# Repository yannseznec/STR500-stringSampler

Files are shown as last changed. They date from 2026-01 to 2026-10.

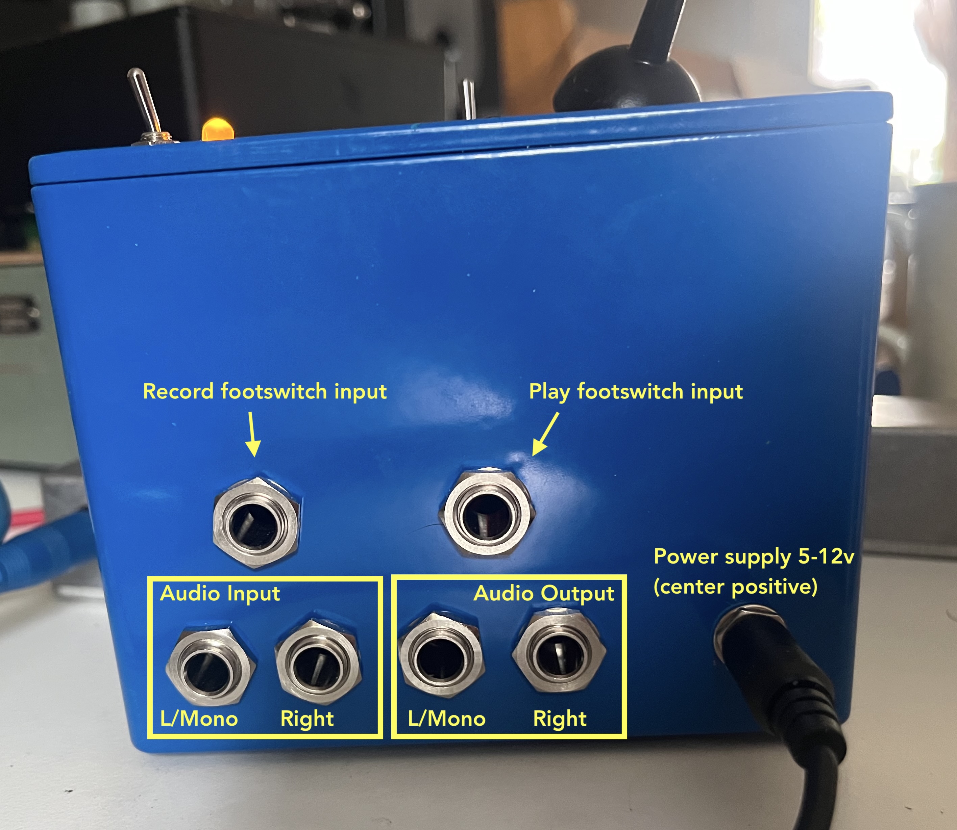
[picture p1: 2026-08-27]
build_notes_etc/STR500_sockets.jpg

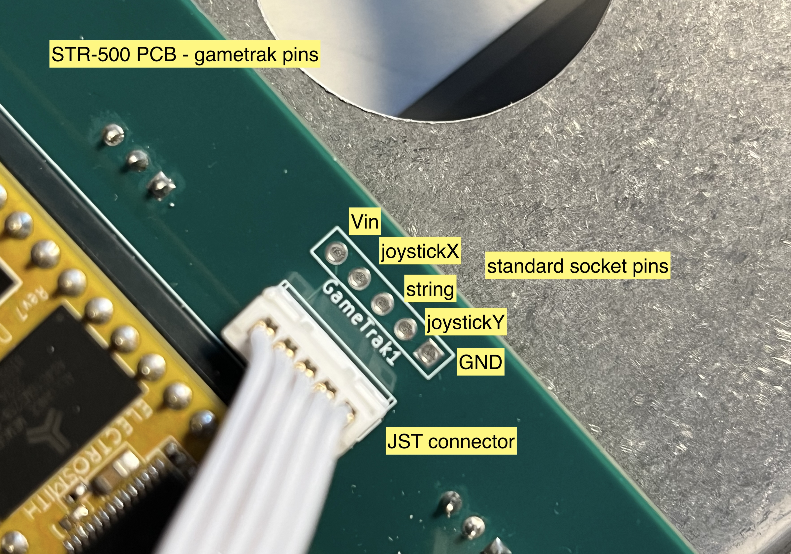
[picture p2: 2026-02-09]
build_notes_etc/picture_gametrak_pins.jpg

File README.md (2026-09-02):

## STR-500

This is all of the code and build info for the STR-500 gestural granular synthesizer. 

It is a granular synthesizer built for the Daisy Seed which uses a salvaged Gametrak string controller to playback a recorded sample. 

Here you will find a Pure Data system for running on the Daisy Seed, a KiCad project with the schematic and PCB design for the instrument, and a folder of information about the physical build. Current working version is called v1.2, and as it stands includes updated code and KiCad (full details on the build are not yet updated).

To-do: 
- develop this Readme
- add an actual to-do list to this Readme

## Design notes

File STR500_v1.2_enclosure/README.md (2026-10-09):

# STR-500 enclosure design 

This folder has the files I use for drilling and etching the enclosure for the STR-500. 

The enclosure I use is a Hammond 1590V. 

The Gametrak string mechanism I'm using is a particular size and shape, which means the enclosure needs to be a certain height and width. I wanted something that I could buy off the shelf (rather than 3D print or build from scratch), and I really like metal enclosures. The Hammond 1590V fulfills all of these requirements - just! It's a very tight fit in there and the holes need to be drilled just right. The only issue is that it's a relatively unusual model, so I can't use the standard drill/paint services that most effects and instrument companies use. 

Instead, the process is: 
• buy the bare metal enclosures
• use a little jig I laser cut to drill all the holes in the enclosure - these have to be pretty accurate because the PCB needs to mount underneath the lid
• get them powder coated blue at an industrial painting place
• put the lids into a laser cutter and etch the powder coating away in the design I want
• fill the etching with a wax crayon, wipe the excess with rubbing alcohol
• light spraypaint for texture

The painting and etching is, of course, totally optional. You can definitely make your own design or just leave it bare metal and unlabeled. 

If you want to follow my own process, the files are all here for you to laser cut your own drill guide. You may find some other useful method for drilling the holes. 

Drilling the holes accurately is challenging! I would recommend first drilling small holes (2-3mm) and then using a stepped bit to get them up to size. The large hole for the Gametrak string is particularly hard to get just right. I usually end up needing to adjust the exact horizontal placement of the Gametrak string using washers on the M5 bolts holding it in place.

Software-wise, the vectors files for the hole locations are made in Affinity, and the laser cutting files are for Lightburn.

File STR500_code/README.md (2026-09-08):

# Granular sampler for Daisy (STR-500)
This is a granular sampling system that runs on a Daisy Seed microcontroller. As the name implies, this is the new version of the code, which I mainly did in an attempt to make it more efficient. That failed, but it resulted in patches that are much cleaner, easier to read, and easier to maintain. So that's something.  

Written in Pure Data. The easiest way to get it running on a Seed is to use PlugData for compiling. I use the "Big + SDRAM" SRAM setting in the compiler to allow for the relatively long sampling time. I set the blocksize to 100 for now. 

This granular patch is essentially the same as the ys.granular system also available here on my github: https://github.com/yannseznec/ys.granular

The main difference is that this version does not use the [clone] object, which is not supported by the Heavy compiler required by the Daisy Seed. There are probably a few other similar changes that I can't remember right now.

This patch is particularly designed for use with a Gametrak string controller, resulting in a gestural sampling machine that I call the STR-500. More details on that coming at some point, you can see videos of it on my instagram if you like: https://www.instagram.com/p/DPdloWzjOOb/

For the STR-500 on Daisy Seed there is a JSON file (STR500_definitions.json) included for getting the interface elements (buttons, switches, Gametrak) connected to the Seed correctly. At some point I'll make a more detailed guide for how to get that to work.

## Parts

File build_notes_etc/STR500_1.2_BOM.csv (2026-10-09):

Part | Number per device | Link | Notes | Secondary link | Notes
IC socket for Daisy | 2 | https://www.electrokit.com/hylslist-2.54mm-1x20p |  | https://se.rs-online.com/web/p/pcb-sockets/2053211
Small buttons | 2 | https://www.electrokit.com/en/tryckknapp-pcb-6x6x12mm-svart
Bigger buttons | 2 | https://se.rs-online.com/web/p/taktila-stromstallare/7651563 |  | https://www.digikey.se/sv/products/detail/mec-switches/5GTH935/2411559 | MEC 5GTH935
Big button caps | 2 | https://se.rs-online.com/web/p/taktila-stromstallartoppar/7651324 |  | https://www.digikey.se/sv/products/filter/tillbehör-lock/210?s=N4IgTCBcDaILYFMDGACAjAEwM4gLoF8g | So many nice colors possible, not all easy to find.
Switches RND 210-00471 | 3 | https://www.electrokit.com/en/vippomkopplare-sub-miniatyr-1-pol-on-on-pcb |  | https://www.digikey.se/en/products/detail/e-switch/200MSP1T1B1M2QEH/378916 | Need to check the Digikey ones to see, I think they are better. Main thing is 3 pin with .1” spacing
Capacitors | 2 |  |  |  | 1 electrolytic 220µf, 1 .1µf ceramic
Resistor | 1 |  |  |  | 220ohm (roughly, for LED)
LED | 1 |  |  |  | I use 5mm
Molex 6pin connectors | 1 | https://www.electrokit.com/en/kontakt-kk-pcb-2.54mm-6-pol | https://se.farnell.com/multicomp-pro/mc34635/header-square-pin-2-54mm-6way/dp/1675768 |  | For the foot switch connector. If not using foot switches you can avoid this and just bridge four pins (see the build notes)
Molex 2pin connectors | 5 | https://se.farnell.com/multicomp-pro/mc34629/header-tht-vertical-2-54mm-2way/dp/1675764 |  |  | For audio in/out and power connector. You can choose other connection options using the 2.54” holes
JST connector | 1 | https://www.electrokit.com/en/stiftlist-ph-5-pol-2.0mm |  |  | For easy Gametrak connection. Other connection options available, see build notes
M5 screws | 4 | https://se.rs-online.com/web/p/maskinskruv/9087719 |  |  | For gametrak mounting. 45 or 50mm
M5 nuts | 4 | https://se.rs-online.com/web/p/sexkantsmuttrar/2874065 |  |  | For gametrak mounting
M5 standoffs | 4 | https://www.electrokit.com/en/distanshylsa-m5-10mm-metall |  | https://www.digikey.se/en/products/detail/würth-elektronik/970120581/6174778 | 12mm might be better! Try them on next Digikey order
M5 hole washers |  |  |  |  | Useful for adjusting Gametrak mounting distance
M3 standoffs | 2 | https://se.rs-online.com/web/p/distansbultar/1842769 |  |  | 8mm. For PCB lid mounting
M3 screws | 2 | https://se.rs-online.com/web/p/maskinskruv/0553396 |  | https://se.rs-online.com/web/p/hylsskruv/4839751 | PCB lid mounting
M3 nuts | 2 | https://se.rs-online.com/web/p/sexkantsmuttrar/0560293 |  |  | PCB lid mounting
Power socket | 1 | https://www.electrokit.com/en/dc-jack-2.1mm-chassi-rund-brytande |  |  | 2.1mm pin
2 pin molex | 5 | https://se.farnell.com/multicomp-pro/mc34481/crimp-housing-2-54mm-2way/dp/1675754 |  |  | If you want to crimp your own
6 wire molex cables | 1 | https://www.electrokit.com/en/kontakthus-kk-med-kabel-6-pol-20cm |  |  | Pre-crimped cables for lazy people like me
2 wire molex cable | 1 | https://www.electrokit.com/en/kontakt-kk-pcb-2.54mm-2-pol |  |  | Pre-crimped cables for lazy people like me
Audio Jack sockets | 6 | https://se.rs-online.com/web/p/jackkontakter-och-uttag/2617666?referrer=distrelec | Amphenol - ACJS-MVS-2S | https://www.digikey.be/en/products/detail/amphenol-sine-systems-corp/ACJM-MVS-2S/10443648 | Switching audio sockets for mono/stereo. See build notes.
Power supply | 1 | https://se.rs-online.com/web/p/acdc-adaptrar/0634220 |  |  | 5-12v, center positive
Enclosure | 1 | https://www.electrokit.com/en/aluminiumlada-gjuten-1590v-ip54-119x119x90mm
Jumper cap | 2 | https://se.rs-online.com/web/p/byglar-och-shuntar/2518682?matchtype=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 |  |  | Optional - for bridging the footswitch pins
Gametrak | 1 |  |  |  | I use the later model gametrak, looks like a TIE fighter, check my videos for more info
Daisy Seed | 1 | https://daisy.audio/products/seed3 |  |  | Older Seed 2 also works

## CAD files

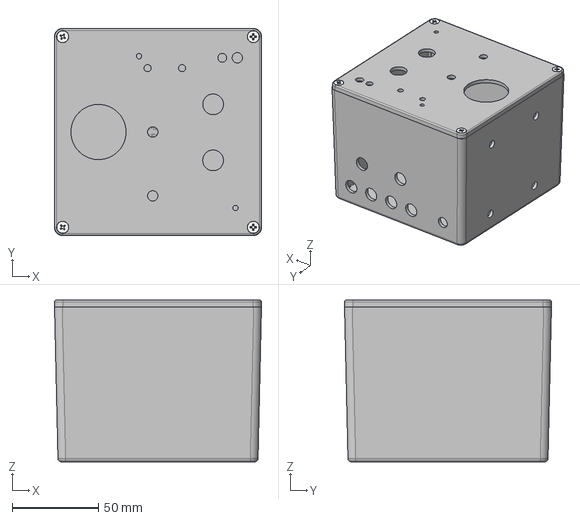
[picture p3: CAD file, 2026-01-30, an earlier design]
old_version_things/STR500_v1.1_enclosure/yanns_box_jan21.step
120.0 x 120.0 x 93.8 mm
1590V Box
1590Q-U-V Lid

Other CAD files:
STR500_v1.2_enclosure/str5001.2_lid_full.dxf
old_version_things/STR500_v1.1_enclosure/STR500_1-1_drill_drawings/STR500+Drawing+gametrak.dwg
old_version_things/STR500_v1.1_enclosure/STR500_DXF_from_PCB/Side_gametrak_drill.dxf
STR500_v1.1_enclosure/STR500_1-1_drill_drawings/STR500+Drawing+lid.dwg
STR500_v1.1_enclosure/STR500_DXF_from_PCB/Side_gametrak_drill.dxf
old_version_things/STR500_v1.1_enclosure/STR500_1-1_drill_drawings/STR500+Drawing+lid.dwg
old_version_things/STR500_v1.1_enclosure/STR500_DXF_from_PCB/Side_sockets_drill.dxf
old_version_things/STR500_v1.1_enclosure/yanns_box.step
STR500_v1.1_enclosure/STR500_1-1_drill_drawings/STR500+Drawing+gametrak.dwg
STR500_v1.1_enclosure/STR500_DXF_from_PCB/Side_sockets_drill.dxf
STR500_v1.1_enclosure/yanns_box.step
old_version_things/STR500_v1.1_enclosure/STR500_1-1_drill_drawings/STR500+Drawing+sockets.dwg
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

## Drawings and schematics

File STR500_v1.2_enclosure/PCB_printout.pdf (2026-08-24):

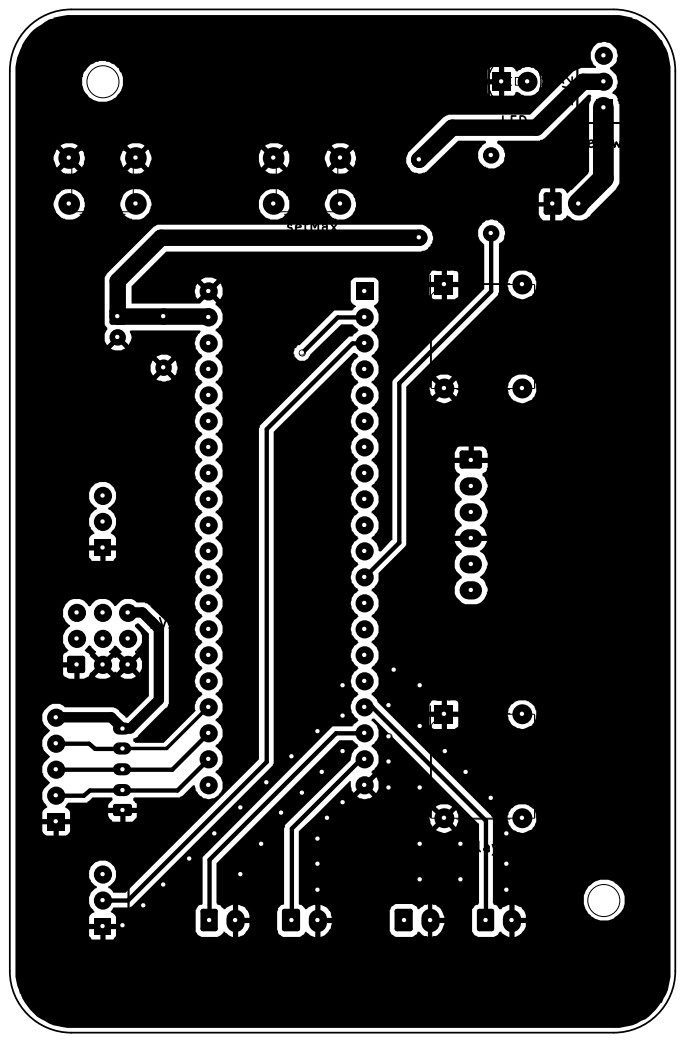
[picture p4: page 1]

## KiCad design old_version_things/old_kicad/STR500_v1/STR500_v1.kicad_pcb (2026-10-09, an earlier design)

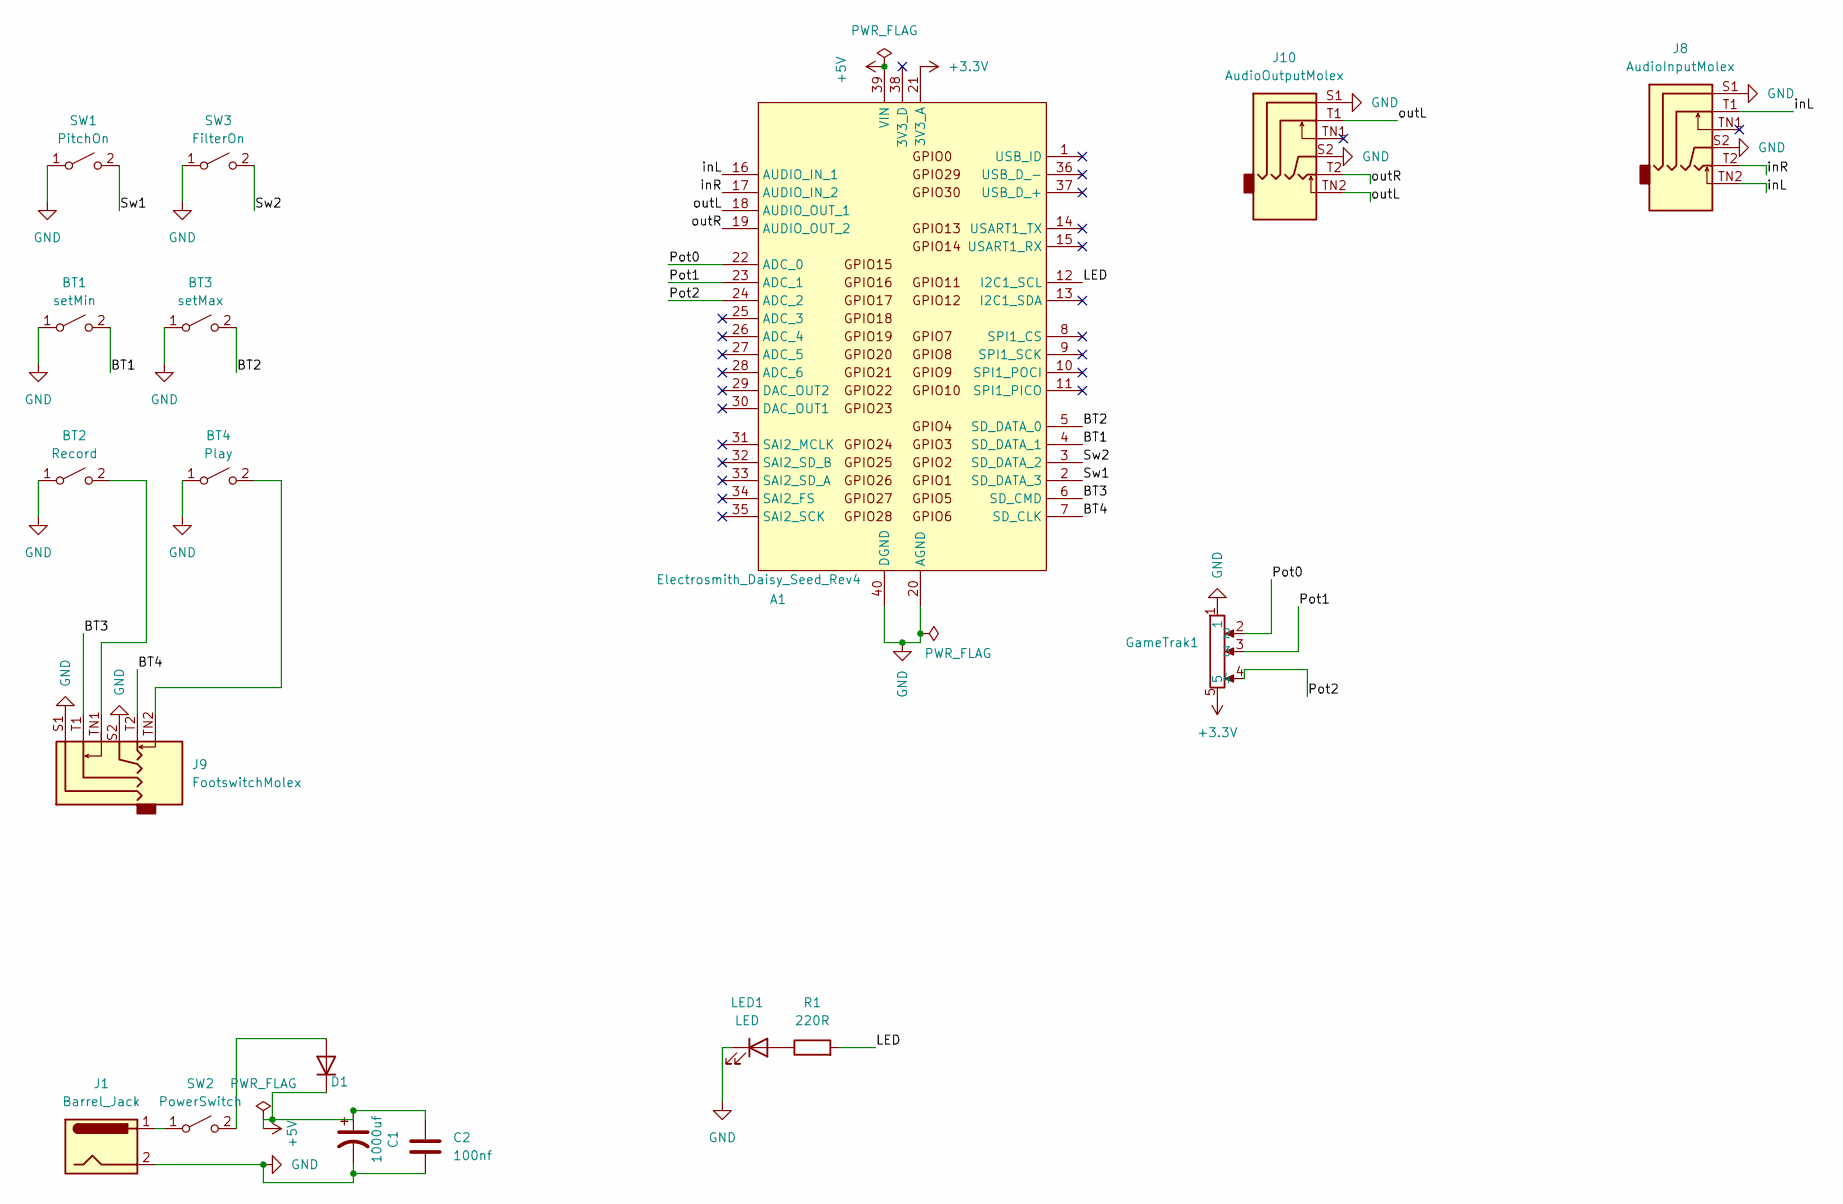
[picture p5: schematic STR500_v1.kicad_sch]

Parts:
A1: Electrosmith_Daisy_Seed_Rev4; Electrosmith_Daisy_Seed
BT1: setMin; SW_PUSH_6mm
BT2: Record; SW_TS13-1212-73-BK-160-D
BT3: setMax; SW_PUSH_6mm
BT4: Play; SW_TS13-1212-73-BK-160-D
C1: 1000uf; CP_Radial_D5.0mm_P2.00mm
C2: 100nf; C_Disc_D5.0mm_W2.5mm_P5.00mm
D1: D; R_Axial_DIN0207_L6.3mm_D2.5mm_P7.62mm_Horizontal
GameTrak1: Molex_Micro-Latch_53253-0570_1x05_P2.00mm_Vertical
J1: Barrel_Jack; Molex_KK-254_AE-6410-02A_1x02_P2.54mm_Vertical
J8: AudioInputMolex; Molex_sixpin_twoJacks
J9: FootswitchMolex; Molex_sixpin_twoJacks
J10: AudioOutputMolex; Molex_sixpin_twoJacks
LED1: LED; LED_D5.0mm
R1: 220R; R_Axial_DIN0207_L6.3mm_D2.5mm_P7.62mm_Horizontal
SW1: PitchOn; submini_toggle
SW2: PowerSwitch; submini_toggle
SW3: FilterOn; submini_toggle

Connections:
+3.3V: A1.21 (3V3_A), GameTrak1.5
+5V: A1.39 (VIN), C1.1, C2.1, D1.1 (K)
/BT1: A1.4 (SD_DATA_1), BT1.2 (B)
/BT2: A1.5 (SD_DATA_0), BT3.2 (B)
/BT3: A1.6 (SD_CMD), J9.T1
/BT4: A1.7 (SD_CLK), J9.T2
/LED: A1.12 (I2C1_SCL), R1.2
/Pot0: A1.22 (ADC_0), GameTrak1.2
/Pot1: A1.23 (ADC_1), GameTrak1.3
/Pot2: A1.24 (ADC_2), GameTrak1.4
/Sw1: A1.2 (SD_DATA_3), SW1.2 (B)
/Sw2: A1.3 (SD_DATA_2), SW3.2 (B)
/inL: A1.16 (AUDIO_IN_1), J8.T1, J8.TN2
/inR: A1.17 (AUDIO_IN_2), J8.T2
/outL: A1.18 (AUDIO_OUT_1), J10.T1, J10.TN2
/outR: A1.19 (AUDIO_OUT_2), J10.T2
GND: A1.20 (AGND), A1.40 (DGND), BT1.1 (A), BT2.1 (A), BT3.1 (A), BT4.1 (A), C1.2, C2.2, GameTrak1.1, J1.2, J8.S1, J8.S2, J9.S1, J9.S2, J10.S1, J10.S2, LED1.1 (K), SW1.1 (A), SW3.1 (A)
unnamed: BT2.2 (B), J9.TN1
unnamed: BT4.2 (B), J9.TN2
unnamed: D1.2 (A), SW2.2 (B)
unnamed: LED1.2 (A), R1.1
unnamed: J1.1, SW2.1 (A)

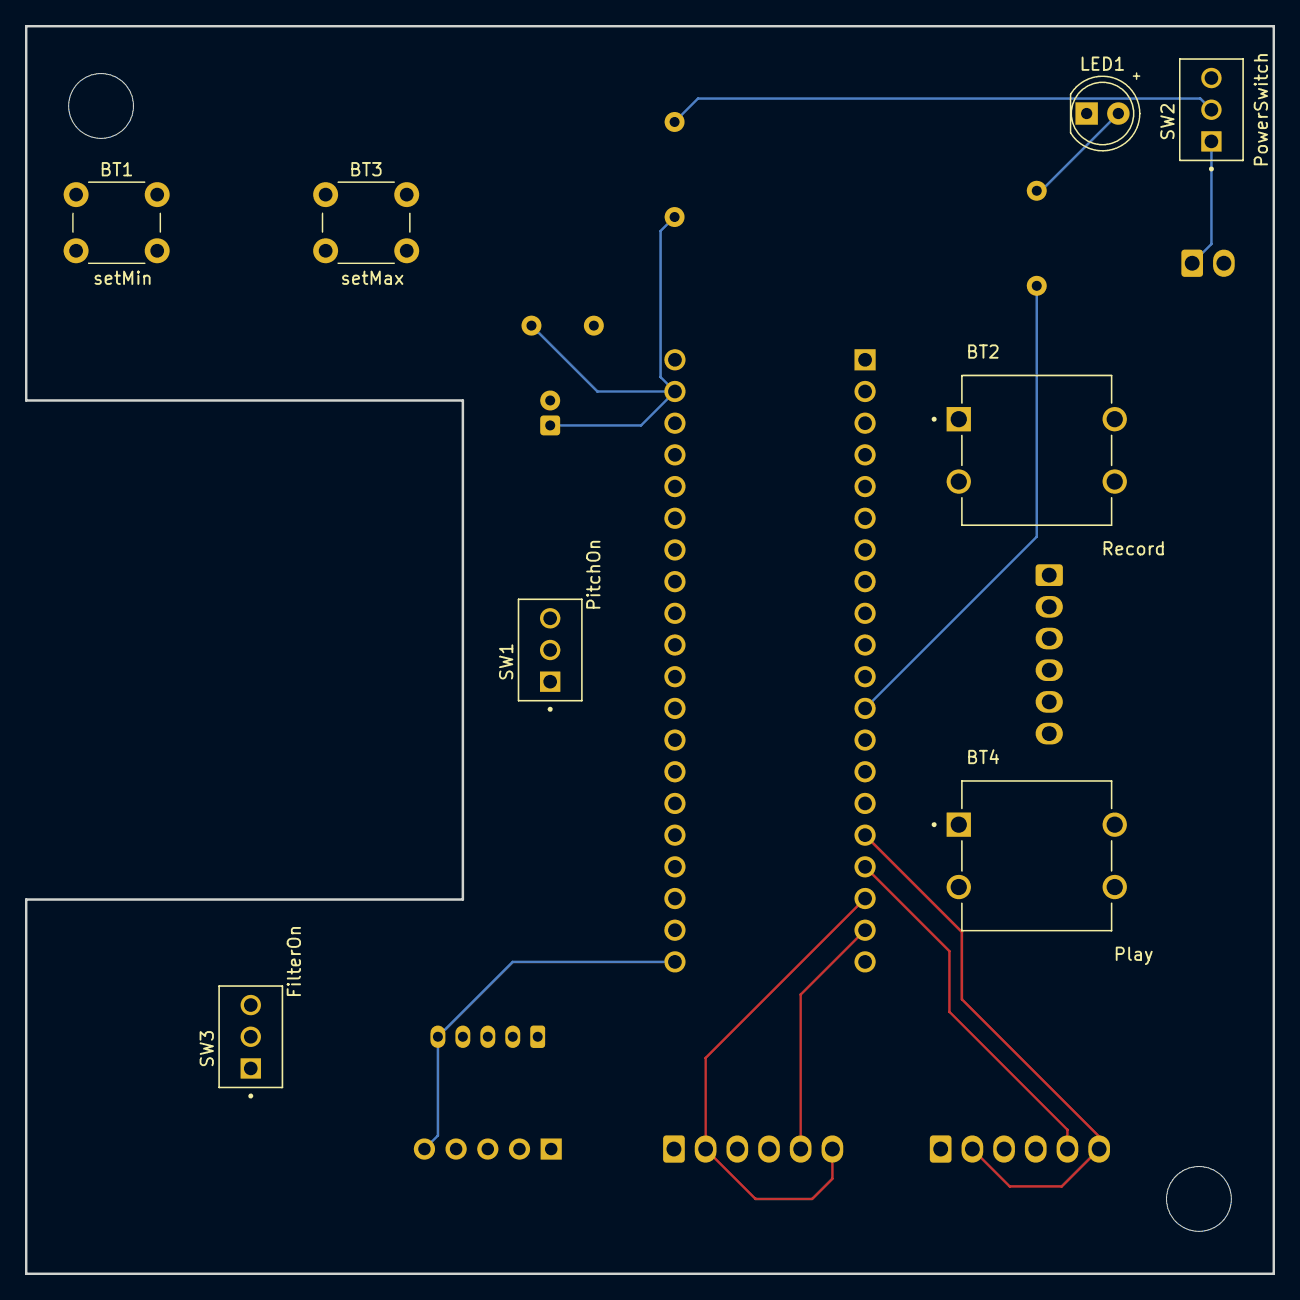
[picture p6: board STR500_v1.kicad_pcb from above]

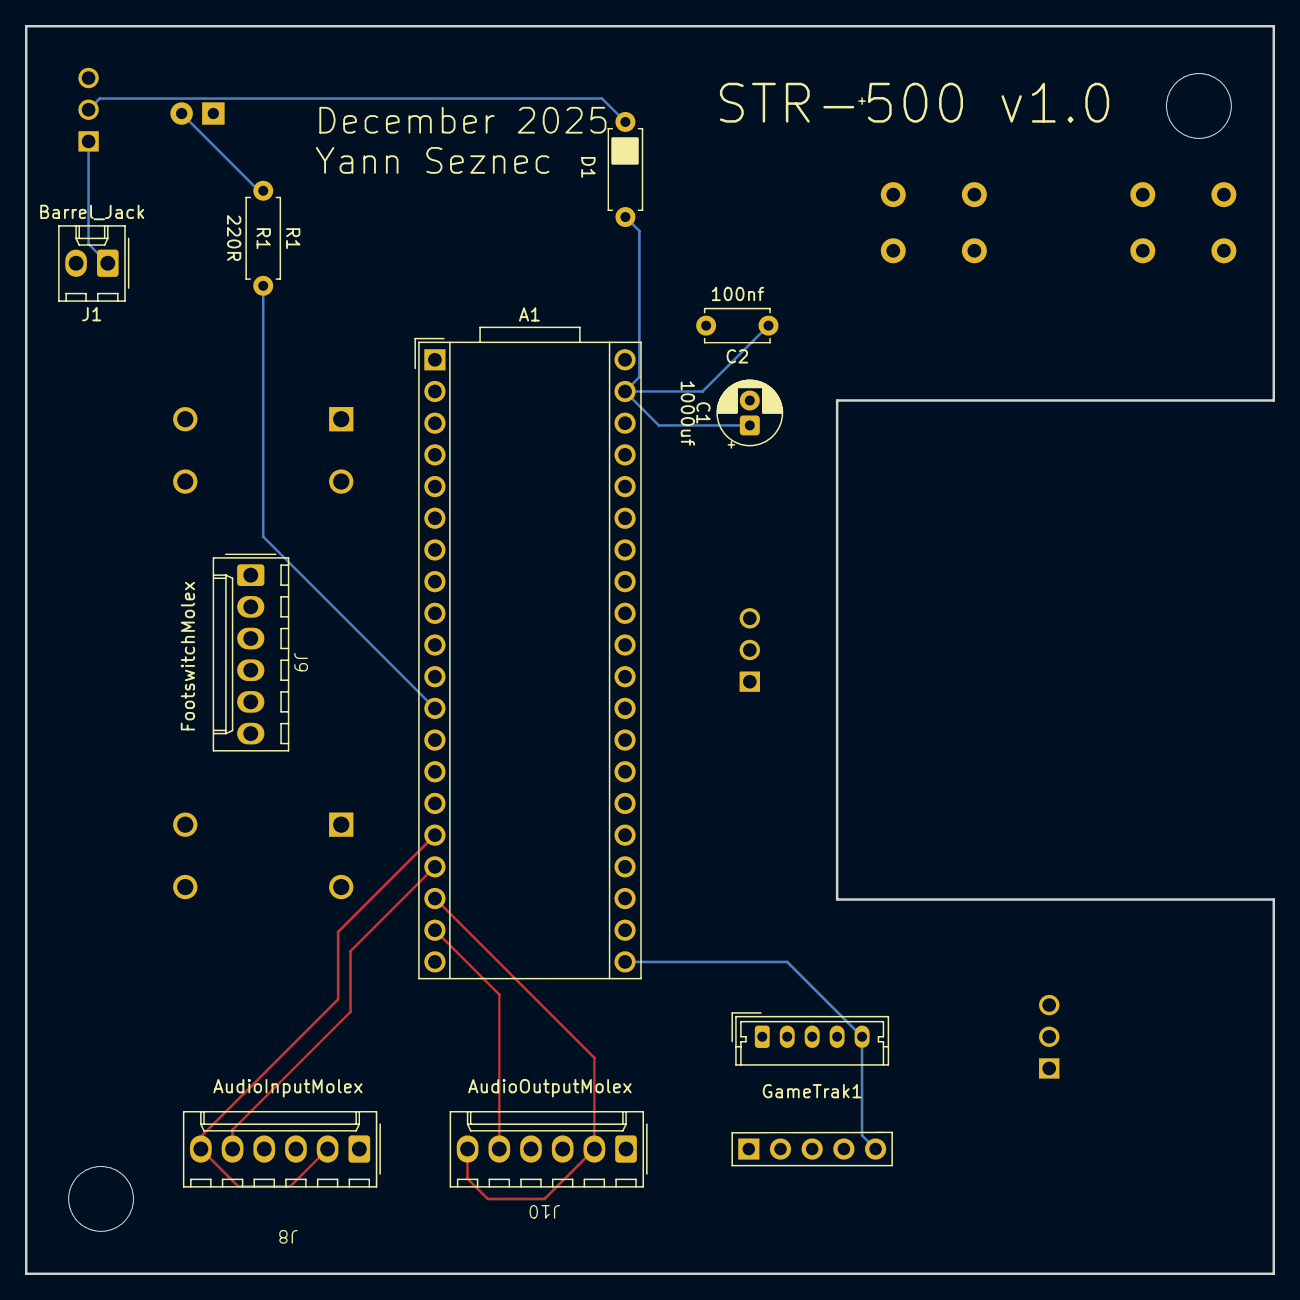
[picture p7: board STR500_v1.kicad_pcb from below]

Board: 4 copper layers, 100.0 x 100.0 mm, 18 parts (10 on the bottom side), 22 nets.

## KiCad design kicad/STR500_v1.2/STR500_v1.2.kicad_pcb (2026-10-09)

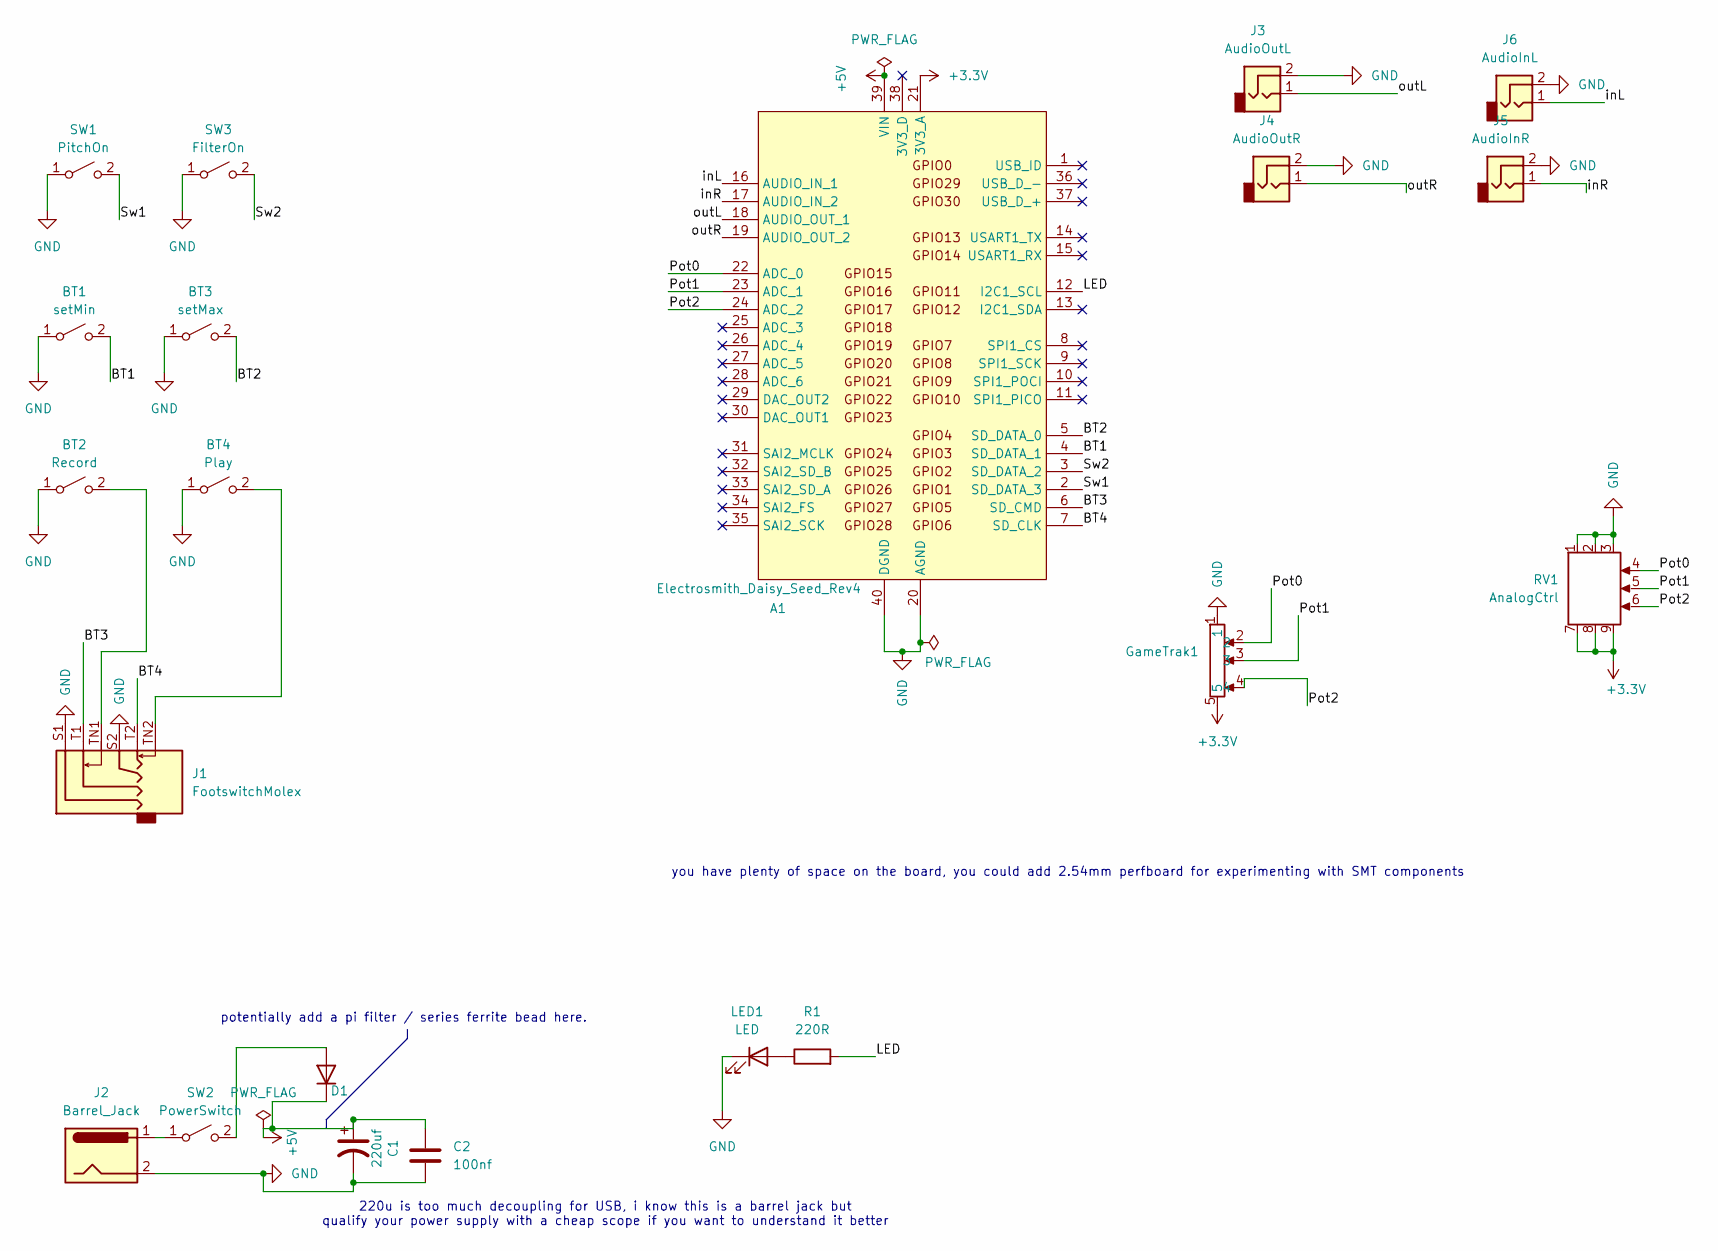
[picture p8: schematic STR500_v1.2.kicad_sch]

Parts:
A1: Electrosmith_Daisy_Seed_Rev4; Electrosmith_Daisy_Seed
BT1: setMin; SW_PUSH_6mm
BT2: Record; SW_MEC_5GTH9
BT3: setMax; SW_PUSH_6mm
BT4: Play; SW_MEC_5GTH9
C1: 220uf; CP_Radial_D5.0mm_P2.00mm
C2: 100nf; C_Disc_D5.0mm_W2.5mm_P5.00mm
D1: D; R_Axial_DIN0207_L6.3mm_D2.5mm_P7.62mm_Horizontal
GameTrak1: Molex_Micro-Latch_53253-0570_1x05_P2.00mm_Vertical
J1: FootswitchMolex; Molex_sixpin_twoJacks
J2: Barrel_Jack; Molex_KK-254_AE-6410-02A_1x02_P2.54mm_Vertical
J3: AudioOutL; Molex_KK-254_02_pin
J4: AudioOutR; Molex_KK-254_02_pin
J5: AudioInR; Molex_KK-254_02_pin
J6: AudioInL; Molex_KK-254_02_pin
LED1: LED; LED_D5.0mm
R1: 220R; R_Axial_DIN0207_L6.3mm_D2.5mm_P7.62mm_Horizontal
RV1: AnalogCtrl; IDC-Header_2x03_P2.54mm_Vertical
SW1: PitchOn; submini_toggle
SW2: PowerSwitch; submini_toggle
SW3: FilterOn; submini_toggle

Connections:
+3.3V: A1.21 (3V3_A), GameTrak1.5, RV1.7, RV1.8, RV1.9
+5V: A1.39 (VIN), C1.1, C2.1, D1.1 (K)
/BT1: A1.4 (SD_DATA_1), BT1.2 (B)
/BT2: A1.5 (SD_DATA_0), BT3.2 (B)
/BT3: A1.6 (SD_CMD), J1.T1
/BT4: A1.7 (SD_CLK), J1.T2
/LED: A1.12 (I2C1_SCL), R1.2
/Pot0: A1.22 (ADC_0), GameTrak1.2, RV1.4
/Pot1: A1.23 (ADC_1), GameTrak1.3, RV1.5
/Pot2: A1.24 (ADC_2), GameTrak1.4, RV1.6
/Sw1: A1.2 (SD_DATA_3), SW1.2 (B)
/Sw2: A1.3 (SD_DATA_2), SW3.2 (B)
/inL: A1.16 (AUDIO_IN_1), J6.1
/inR: A1.17 (AUDIO_IN_2), J5.1
/outL: A1.18 (AUDIO_OUT_1), J3.1
/outR: A1.19 (AUDIO_OUT_2), J4.1
GND: A1.20 (AGND), A1.40 (DGND), BT1.1 (A), BT2.1 (A), BT3.1 (A), BT4.1 (A), C1.2, C2.2, GameTrak1.1, J1.S1, J1.S2, J2.2, J3.2, J4.2, J5.2, J6.2, LED1.1 (K), RV1.1, RV1.2, RV1.3, SW1.1 (A), SW3.1 (A)
unnamed: BT2.2 (B), J1.TN1
unnamed: BT4.2 (B), J1.TN2
unnamed: D1.2 (A), SW2.2 (B)
unnamed: LED1.2 (A), R1.1
unnamed: J2.1, SW2.1 (A)

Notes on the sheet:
potentially add a pi filter / series ferrite bead here.
you have plenty of space on the board, you could add 2.54mm perfboard for experimenting with SMT components
220u is too much decoupling for USB, i know this is a barrel jack but qualify your power supply with a cheap scope if you want to understand it better

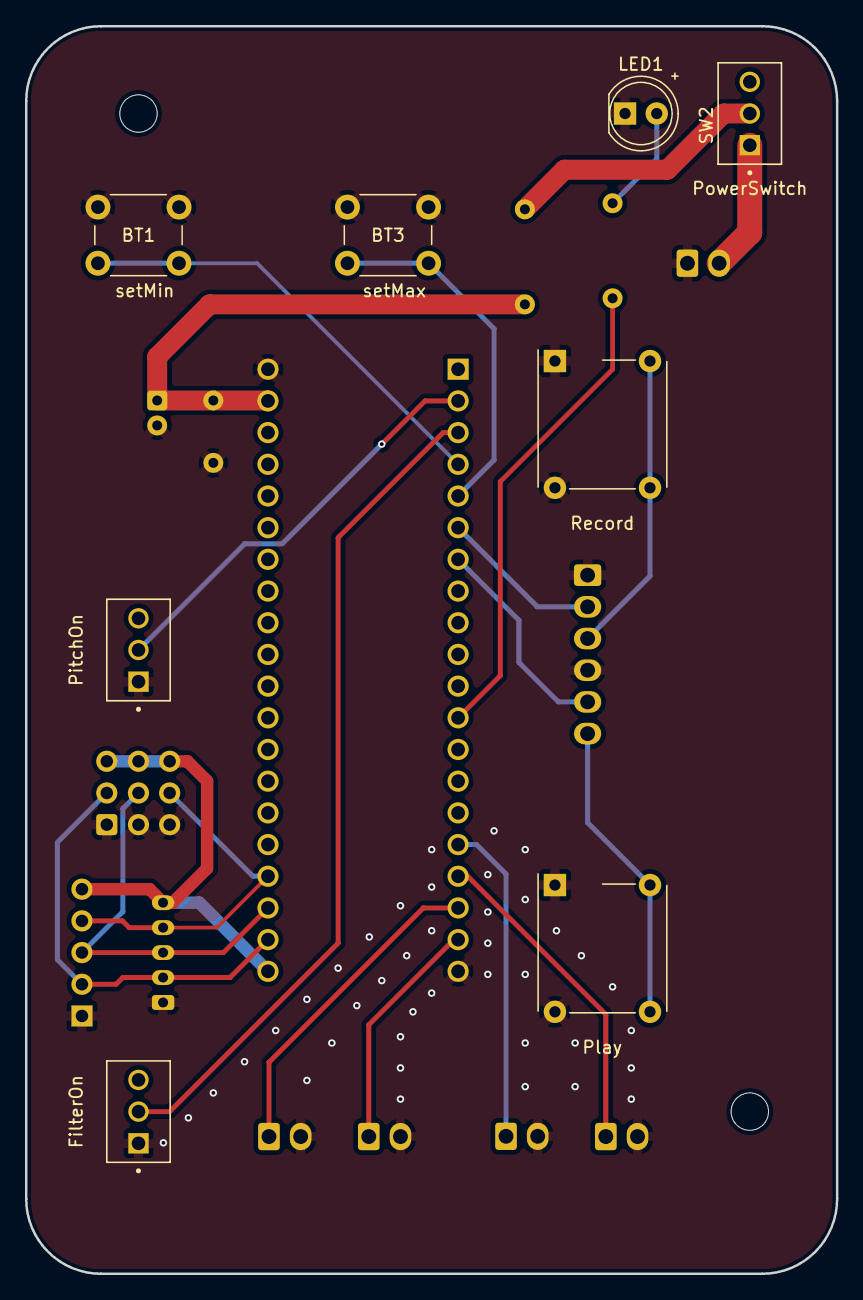
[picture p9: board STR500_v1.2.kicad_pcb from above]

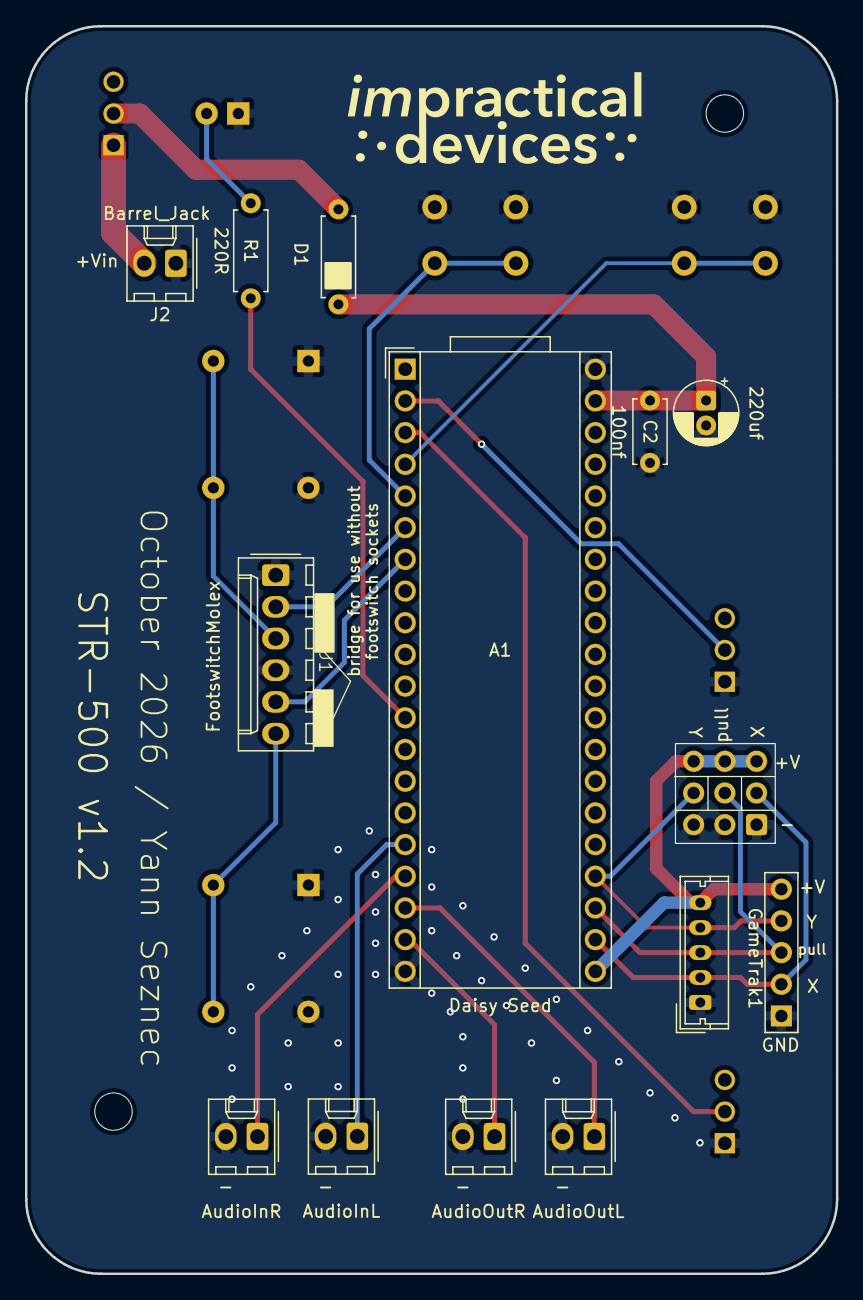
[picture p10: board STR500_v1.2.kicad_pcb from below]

Board: 2 copper layers, 65.0 x 100.0 mm, 21 parts (13 on the bottom side), 22 nets.

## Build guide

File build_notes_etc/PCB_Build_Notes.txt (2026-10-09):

### STR500 Build notes (v1.2)

## Wiring the Molex connectors
For ease of build I used pre-wired 6-way Molex connectors for the footswitch controls. I also use pre-wired 2-way connectors for Power and Audio input/output. These attach to standard molex pins on the PCB. They use standard 2.54" hole distances, so other methods are possible.

Check the pictures for information on how to wire the footswitches and audio connectors. Be sure to mount the molex sockets in the correct orientation to ensure that the color coding makes sense.

Audio Inputs and Outputs (these are identical)
- to do: fill this out and add photos

Footswitch connector:

- Brown: Playback GND pin
- Red: Playback Tip pin
- Orange: Playback Switch pin
- Yellow: Record GND pin
- Green: Record Tip pin
- Blue: Record Switch pin

Pictures are included in this repo (need to add more!). 

# Gametrak
For my builds of the STR-500 I use a second generation Gametrak, which is easiest to disassemble and reassemble into a new container. See this video for info on how to hack: https://youtu.be/JUrJCBs35Bo 

When you disassemble a second generation Gametrak you will get two string cartridges. Each cartridge has wires connected to the string and joystick with a 5 pin JST connector. On the PCB you have two choices:
1. use an identical JST connector to the one on the Gametrak, and connect the gametrak to the PCB using a socket-to-socket five pin JST cable (you can buy these premade or crimp them yourself)
2. solder some 2.54" pins to the PCB and connect the gametrak to those somehow, either soldering the wires to the PCB or crimping 2.54" pins onto the Gametrak wires. When you hack out a second generation Gametrak the wires are color-coded, and the order needs to be preserved to work on the PCB. These are:
- Green: Power
- Yellow: Joystick X (or Y? it's sometimes difficult to guess)
- Orange: string pull distance
- Red: Joystick Y (or X...)
- Brown: Ground

You can also connect any potentiometers or analog inputs to these pins! You'll just need to figure out how to connect all three to the single power pin and single ground pin. The v2.1 version of the PCB has extra 2.54" pin sockets for anyone who wants to connect normal potentiometers more easily or if you want to hack an earlier model Gametrak. The first version Gametrack did not have unified power and ground pins, and the string is not as usefully self-contained. To-do: make a guide for connecting any analog inputs to these pins.

# Capacitors
These are kind of optional, they should theoretically lessen the noise on the audio output. Different values may give you different results, and the audio will work perfectly fine without them (albeit with some noise). 

# Buttons
I use nice MEC buttons for the bigger buttons. The smaller buttons are generic 6x6x13 tactile buttons, you can probably find different ones from the ones on the BOM. 

# Daisy Seed & Pure Data
See the STR500_code folder for the code and some information on how to load it onto the Seed.

# Check the KiCAD
This repo also has the KiCAD project included so you can check the circuit and layout if you aren't sure (and if you know how to use KiCAD!).

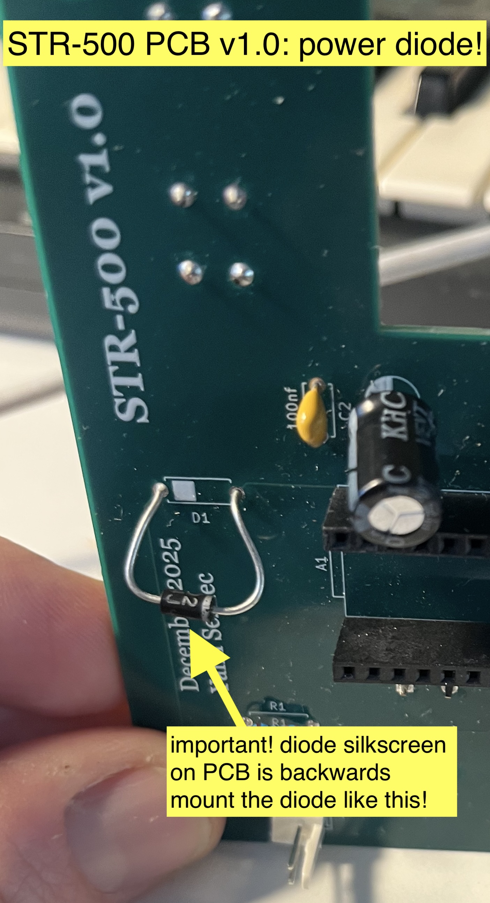
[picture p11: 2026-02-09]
build_notes_etc/picture_1.0_diode.jpg

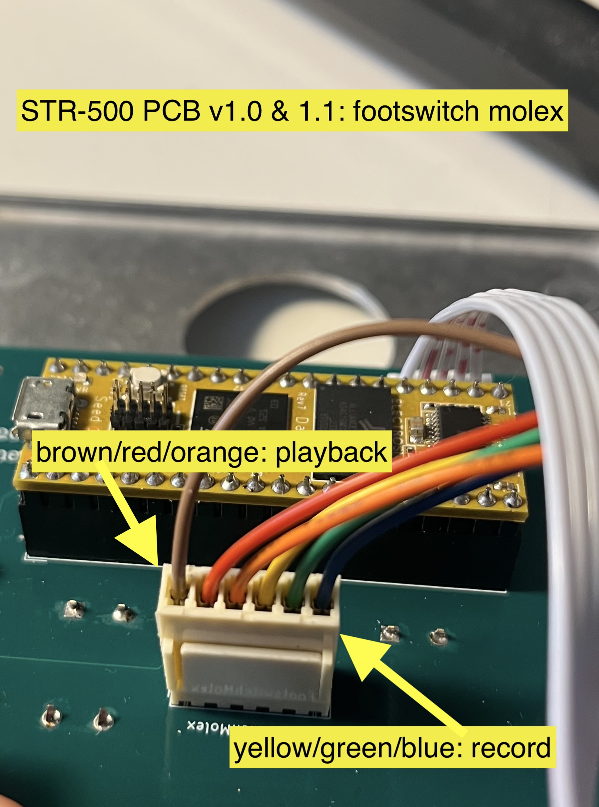
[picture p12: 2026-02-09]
build_notes_etc/picture_footswitch_molex.jpg

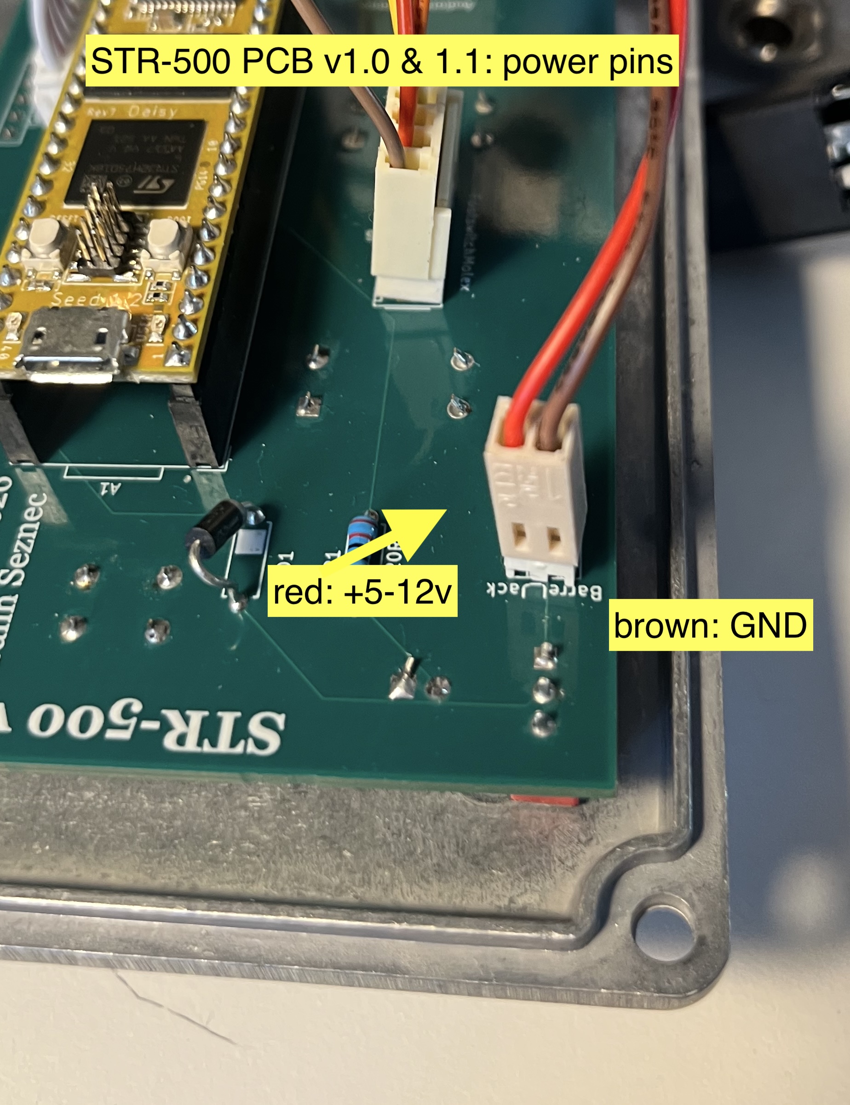
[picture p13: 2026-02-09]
build_notes_etc/picture_power.jpg

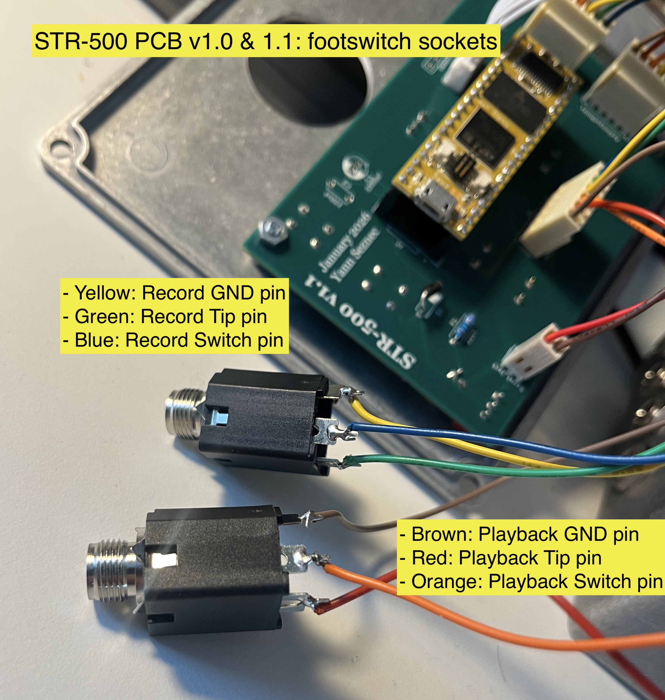
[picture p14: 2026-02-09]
build_notes_etc/picture_footswitch_sockets.jpg

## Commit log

2025-11-06 First commit of string sampler STR-500
2025-11-06 changed the filter slightly
2026-01-21 drill files etc
    [str500v1.1_holes.dxf]
2026-01-21 more drill files
    [Side_gametrak_drill.dxf, Side_sockets_drill.dxf]
2026-01-30 3d models, notes
    [yanns_box.step, yanns_box.stl, yanns_box_jan21.step]
2026-02-05 file reorganize
    [STR500+Drawing+gametrak.dwg, STR500+Drawing+gametrak.f3z, STR500+Drawing+lid.dwg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]
2026-02-09 Update PCB Build Notes
2026-07-14 new PCB version and many other changes i forgot
    [STR500_v1.2.kicad_pcb, STR500_v1.2.kicad_sch]
2026-07-20 rerouted as 2L
    [STR500_v1.2.kicad_pcb, STR500_v1.2.kicad_sch]
2026-08-20 small changes to PCB, renaming JSON file
    [STR500_v1.2-B_Cu.gbl, STR500_v1.2-B_Mask.gbs, STR500_v1.2-B_Paste.gbp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]
2026-08-24 starting the new enclosure build
    [str5001.2_lid_full.dxf]
2026-08-25 laser etching files
2026-08-27 fixed long-sample-recording issue
    also renamed the JSON file, updated readme, added some hardware files
    [STR500+Drawing+gametrak.dwg, STR500+Drawing+gametrak.f3z, STR500+Drawing+lid.dwg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]
2026-09-02 more grains!
    raised number of grains to 10, for use with higher block sizes. also improved string scaling, tweaked filter, and removed vestigial things
2026-10-06 update BOM
2026-10-09 cosmetic update to PCB
    [STR500_v1.2.kicad_pcb]
2026-10-09 cleanup, tweak PCB, new fabrication files
    [STR500+Drawing+gametrak.dwg, STR500+Drawing+gametrak.f3z, STR500+Drawing+lid.dwg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]
2026-10-09 update BOM and build info text
    [STR500_1.2_BOM.csv]
2026-10-15 build guide update, mainly PCB
2026-10-23 PCB build instructions
2026-11-09 updating the PCB to fix small mistakes, update BOM
2026-11-12 PCB mistake fixed
2026-11-12 new fabrication files for PCB
    aesthetic changes, fixing a few mistakes on the screenprinting
